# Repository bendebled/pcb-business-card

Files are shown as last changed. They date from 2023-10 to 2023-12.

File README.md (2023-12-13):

# pcb-business-card-micropython

Paper business cards have long been a staple of professional networking, but in today's digital age, they can feel a bit outdated. PCB business card is a more dynamic and innovative alternative that showcases your creativity and technical prowess. While paper business cards are traditional and functional, PCB business cards are undeniably more intriguing, making a lasting impression with their unique blend of design and functionality.

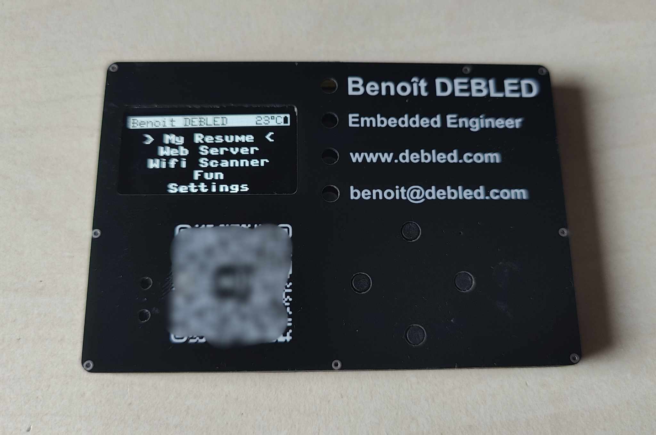
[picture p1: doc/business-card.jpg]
business-card


## Requirements 

Here are the main requirements and features:

1. Usefulness: The PCB business card must break the mold of traditional business cards, ensuring it remains relevant and does not end up in a drawer, forgotten. To achieve this, it will incorporate a range of practical features.
2. Cost-Efficiency: Keeping the project within budget is essential. By selecting cost-effective components and optimizing the design, the aim is to strike a balance between functionality and affordability.
3. Self-Contained Operation: The business card will operate independently, without the need for external devices or connections. It should function as a standalone device, enhancing its versatility and usability.

## Key Features:

* ESP32 Microcontroller: The heart of the card, offering Wi-Fi and Bluetooth capabilities, making it versatile for various projects. Its compatibility with MicroPython allows for easy adaptation.
* OLED Screen Display: A small, yet informative screen to showcase a resume or any other relevant information. A screen is always a valuable addition to any portable project.
* Navigation Buttons: Intuitive buttons for easy screen navigation, ensuring a seamless user experience.
* Temperature Sensor: Practical for various applications, such as a portable thermometer or climate data logging.
* Addressable LED: Adding visual appeal and functionality, the LED can display notifications, status updates, or even be used for creative effects.
* Buzzer: Provides audio feedback, enhancing user interaction and versatility for applications like alarms or notifications.
* Battery-Powered: The card will run on a compact, rechargeable battery LIR2450 , eliminating the need for constant external power sources. This feature allows it to be showcased independently and used in various scenarios, such as a remote control or portable game console.
* Header Pins: Including header pins allows the card to be easily integrated into other projects, extending its functionality beyond a business card.
* MicroPython: MicroPython will accelerate the development process, bringing this project to fruition more efficiently, while also facilitating seamless future firmware customization.

## Component selection

* ESP32-C3: ESP32-C3 is one of the smallest ESP32 chip series, allowing a reduced cost of the project. A module containing the USB-C connector, an LDO regulator, an ESP32-C3, antenna, 2 buttons and breakout pins is used in order to accelerate the development process.
* SSD1306 OLED Screen: This screen is one of the most famous OLED screen in hobbyist projects. The OLED technology will allow a small power consumption.
* WS2812b leds: Those adressable LEDs are affordable and allows to have multiple colors making this PCB business card more versatile
* buttons: regular smd buttons are used in this project. They will be flushed to the top surface making a nice finish. Unfortunately, the ESP32-C3 does not have any touch capable pins making touch buttons more of a hassle as external components necessary.
* passive piezzo buzzer: a very small (5*5*2mm) passive piezzo buzzer will allow multiple tones making it more versatile
* LIR2450 battery: a 120mAH LIR2450 battery will be soldered directly to the PCB without any battery holder in order to gain space
* DS1621 Digital Thermometer: this temperature sensor will give more accurate results than the embedded temperature sensor of the ESP32

## Project structure

This repository contains different folders:

* pcb: contains the different designed PCB using Altium Designer
* src: contains the MicronPython code

## How to make the hardware

* Please produce the 3 different PCB needed for this project: the mainboard, the middle and the top. As the LIR2450 battery is 5mm high, you will need 4 PCB of 1.6mm thick for the middle PCB. There are 3 zip files containing the gerber files; one for each PCB.
* Unsolder the regulator on the ESP32 module. This can be done easily with a hot air gun.
* Solder all components on the mainboard.
* Either connect all PCB by soldering a pin on each visible via or by gluing them together with contact glue. If you choose the glue option, you can still use the via to guide the PCB correctly on top of each other.

## How to deploy the firmware

See [doc/firmware.md](doc/firmware.md) for more details

## How to deploy the micropython app

You can list, get and upload new python file using ampy. To install ampy, please run the following command:

```bash
pip3 install adafruit-ampy
```

To list files, you can run:

```
ampy -p /dev/ttyACM0 ls
```

You should get the following results:

```
/app_secrets.py
/benoit-debled-resume.pdf
/boot.py
/buttons.py
/colorsys.py
/config.py
/display.py
/ds1621.py
/index.html
/led_effect.py
/main.py
/menu.py
/microdot.mpy
/microdot_asyncio.mpy
/music.py
/numberfacts.py
/pong.py
/power_mgmt.py
/resume.py
/settings.py
/sh1106.py
/statemachine.py
/static
/temperature.py
/tetris.py
/webserver.py
```

To deploy the files...TODO

## Yet to test:

* Small PCB were glued vertically between LED lights to avoid any light bleed. However, LED pipes should be placed. A cheap solution to test is to pour transparent silicone inside the fours LED holes.

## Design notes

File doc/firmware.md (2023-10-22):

# Firmware

This project is built on top of MicroPython. As I type those lines, the latest MicroPython version is 1.21 and was released on Oct 6 2023.

However, we can not use the [ESP32-C3 artefact built from MicroPython](https://micropython.org/download/ESP32_GENERIC_C3/) as it misses a [PR](https://github.com/micropython/micropython/pull/9583) that we need for this project. Indeed, the ESP32-C3 does not manage the wake-up events from deepsleep like the other ESP32. Due to this, MicroPython does not implement any wake-up event except timer wake-up. We indeed need to be able to wake up the ESP32 when you press on any buttons.

This documents aims to explain how to correctly build a MicroPython that suits our needs

## Build MicroPython firmware

MicroPython uses the ESP-IDF SDK in order to build ESP32 artefacts. You can see in the `ports/esp32/README.md` file that it uses the 5.0.2 SDK version. You can also see that by running the following lines in the REPL of a flashed firmware on a ESP32-C3 chip:

```python
>>> import platform
>>> platform.platform()
MicroPython-1.21.0-riscv-IDFv5.0.2-with-newlib4.1.0

>>> import os
>>> os.uname()
(sysname='esp32', nodename='esp32', release='1.21.0', version='v1.21.0 on 2023-10-06', machine='ESP32C3 module with ESP32C3')
```

Let's get the micropython repository ready:

```bash
git clone git@github.com:micropython/micropython.git
cd micropython
git checkout v1.21.0
gh pr checkout 9583
git rebase v1.21.0
```

The `ports/esp32/README.md` files explains very well how to build a MicroPython firmware for the ESP32 target, but in a nutshell, here is what you need to do:

```bash
git clone -b v5.0.2 --recursive https://github.com/espressif/esp-idf.git
cd esp-idf
./install.sh
source export.sh

cd ../micropython
make -C mpy-cross
cd ports/esp32
make BOARD=ESP32_GENERIC_C3 submodules
make BOARD=ESP32_GENERIC_C3
```

The generated firmware will be here: `build-ESP32_GENERIC_C3/firmware.bin`

Next step: deploy the firmware to the target!

## Deploy MicroPython firmware

If you are lucky, you can just run the following commands: 

```bash
esptool.py --chip esp32c3 --port /dev/ttyACM0 erase_flash
esptool.py --chip esp32c3 --port /dev/ttyACM0 --baud 460800 write_flash -z 0x0 firmware.bin
```

This works on a non-modified ESP32-C3 module. As soon as I removed the LDO that was on the module, this would not work anymore... Indeed, I would get the following error when running the erase_flash command.

```
Serial port /dev/ttyUSB0
Connecting....
Detecting chip type... Unsupported detection protocol, switching and trying again...
Connecting....
Detecting chip type... ESP8266
Chip is ESP8266EX
Features: WiFi
Crystal is 26MHz
MAC: 34:94:54:61:ac:3b
Uploading stub...
Running stub...
Stub running...

A fatal error occurred: Unable to verify flash chip connection (No serial data received.).
```

The [stub](https://docs.espressif.com/projects/esptool/en/latest/esp32/esptool/flasher-stub.html) seems to be blocked somehow...

By doing what [lewisxhe suggested](https://github.com/Xinyuan-LilyGO/T-Display-S3/issues/162), you should be able to run the erase command

```
insert USB, press and hold BOOT, do not release the boot button, then press RST. Finally, release the boot
```

After this procedure, run the erase_flash command and voilà!

The write_flash command should run without any issue!

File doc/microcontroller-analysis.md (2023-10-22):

# Micro-controller analysis

## Introduction

As stated in the readme.md of the roof of this project, the selected micro-controller should have the following requirements:

* Not only useful for this business card, but also useful for any future use
* cost should not be too high

It is also best if the micro controller does not require a lot of external components in order to eventually reduce the cost and also to reduce the pcb footprint and hassle

For those reasons, ESP32 chip family seems to be a good choice: it has small footprint, not too expensive, has a lot of features such as WiFi, BLE,... Moreover, some of them have an onboard flash and USB making it very small

## ESP32 Chip series comparison

The ideal chip would then be a chip that has USB, onboard flash and small current consumption particularly on sleep mode.

Let's first understand the differenc chip series. [This](https://core-electronics.com.au/guides/esp-32-naming-conventions/) website is quite an help to understand the overall differences:

```
    ESP32-SX versions are the most powerful, most current version of these ESP32 boards that are readily available. These boards may or may not have Bluetooth connectivity.
    The S3 variant in particular are built with Edge AI machine-learned systems in mind.  Edge just means all calculations are done on the hardware, not the cloud, check out the ESP32-S3.
    ESP32-CX versions are the Low Power, Lower Peripheries (IO) boards. They are usually drop-in replacements for the original ESP8266 Module. The ESP8266 Module started production all the way back in 2014. These have Bluetooth and WiFi connectivity. Perfect for battery-powered remote systems where a low current draw for a long life is ideal. A great example of this would be the ESP32-C3.
    ESP32-HX versions are coming soon. Espressif is always innovating and producing new solutions to stay in front of the curve. These are oriented towards IoT applications, the H2 features onboard Zigbee. We try to stay on top as well and as such it is worth noting the ESP32-H2 will be available in the very soon future. This will be the next most powerful ESP32 Board.
```

Seems like an ESP32-C3 is the ideal candidate as it is a chip from the C-series, hence the low power series! The ESP32-C3 has onboard flash, onbaord USB and is very inexpensive,... It can be seen as the next generation of the ESP8266 [[ref](https://hackaday.com/2021/02/08/hands-on-the-risc-v-esp32-c3-will-be-your-new-esp8266/)]

Let's see the ESP32-C3 datasheet compared to the other ESP32 chip series:

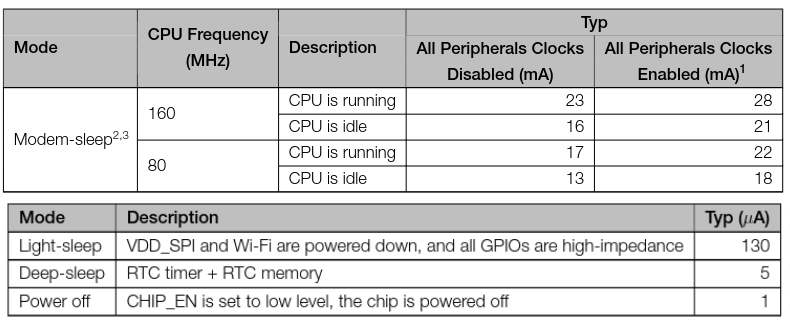
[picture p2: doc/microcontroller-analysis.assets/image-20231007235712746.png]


When the device will be sitting, we should be able to get as low as 5µA which is very good!

On an original ESP32, deep-sleep can go as low as 10µA or can go down to 5µA (hibernation):

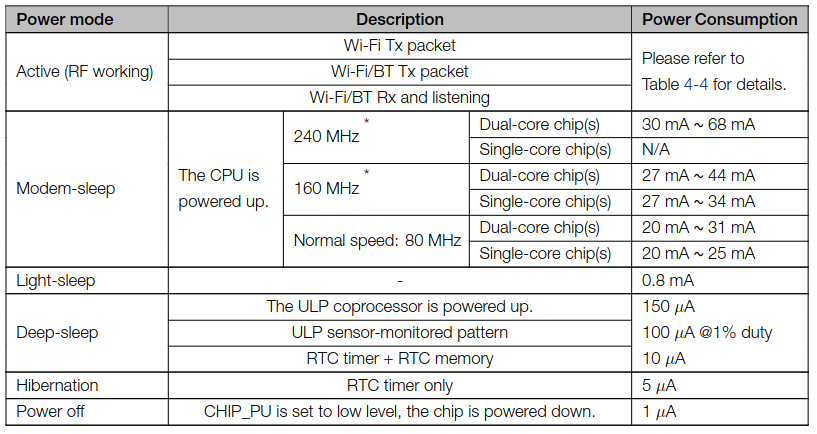
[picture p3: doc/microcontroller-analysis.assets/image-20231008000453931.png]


On the ESP32-S3, deepsleep can go as low as 7µA:

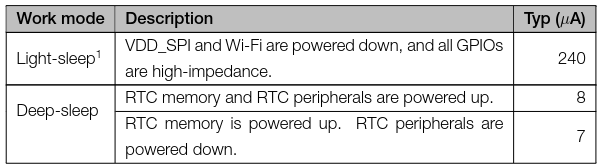
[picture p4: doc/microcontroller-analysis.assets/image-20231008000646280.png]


The following table [[src](https://www.espboards.dev/blog/esp32-soc-options/)] explains very well the differences between the different ESP32 versions

| | ESP32 | ESP32S2 | ESP32S3 | ESP32C2 | ESP32C3 | ESP32C5 | ESP32C6 |
| --- | --- | --- | --- | --- | --- | --- | --- |
| **Release date** | 2016 | 2020 | 2020 | 2022 | 2020 | 2022 | 2021 |
| **Processor** | Xtensa dual-core 32bit LX6 | Xtensa single-core 32bit LX7 | Xtensa dual-core 32bit LX7 | 32bit single-core RISC-V | 32bit single-core RISC-V | 32bit single-core RISC-V | 32bit single-core RISC-V  |
| **Frequency** | 240 MHz | 240MHz | 240 MHz | 120 MHz | 160 MHz | 240 MHz | 160 MHz |
| **SRAM** | 520 KB | 320 KB | 512 KB | 272 KB | 400 KB | 400 KB | 512 KB |
| **ROM** | 448 KB | 128 KB | 384 KB | 576 KB | 384 KB | 384 KB | 320 KB |
| **Flash** | Up to 4 MB | Up to 4 MB | Up to 8 MB | Up to 4 MB | Up to 4 MB | Up to 4 MB | Up to 4 MB |
| **WiFi** | 802.11 b/g/n, 2.4 GHz | 802.11 b/g/n, 2.4 GHz | 802.11 b/g/n, 2.4 GHz | 802.11 b/g/n, 2.4 GHz | 802.11 b/g/n, 2.4 GHz | 802.11 ax, 5.0 GHz | 802.11 ax, 2.4 GHz |
| **Bluetooth** | BLE 4.2 | x | BLE 5.0 | BLE 5.0 | BLE 5.0 | BLE 5.2 | BLE 5.3 |
| **GPIO** | 34 | 43 | 45 | 14 | 22 | 20 | 30 |
| **ADC** | Two 12-bit, 18 channels | Two 13-bit, 20 channels | Two 12-bit, 20 channels | One 12-bit, 5 channels | Two 12-bit, 6 channels | One 12-bit, x channels | One 12-bit, 7 channels |
| **DAC** | Two 8-bit channels | Two 8-bit channels | x | x | x | x | x |
| **SPI** | 4 | 4 | 4 | 3 | 3 | 2 | 2 |
| **I2C** | 2 | 1 | 2 | 1 | 1 | 2 | 2 |
| **I2S** | 2 | 1 | 2 | 1 | 1 | 1 | 1 |
| **RMT** | 8 channels | 4 channels | 8 channels | | 4 channels | 2 channels | 2 channels |
| **Touch sensor** | 10 | 14 | 14 | x | x | x | x |
| **Hall sensor** | 1 | x | x | x | x | x | x |
| **LCD Interface** | 1 | 1 | 1 | x | x | x | x |
| **Camera Interface** | 1 | 1 | 1 | x | x | x | x |
| **Deep sleep** | 100uA | 22uA | 7uA | 5uA | 5uA | 5uA | 7uA |
| **Size** | 5x5mm or 6x6mm | 7x7mm | 7x7mm | 4x4mm | 5x5mm | 5x5mm | 5x5mm |
| **Other features** | | | | | | | 802.15.4 (Thread, Zigbee) |

As it can be seen, the C3 is a good choice as we do not need more than a 802.11 b/g/n wifi, BLE 5.0, 400 KB of RAM and 384 KB of ROM. Moreover, as it is the first one of the series, it is one of the most well known variant and is easy to find on the market!

## ESP32-C3 and deepsleep

Whereas a lot of wake up methods are available on an original ESP32: wake on timer, wake on touch, wake on ulp, wake on ext0, wake on ext1 it is not the case on the ESP32-C3. Indeed, the only possible way to wake up the ESP32-C3 is through a timer or via the pins that are powered by the RTC:



Note that unlike the ESP8266, the ESP32-C3 can sleep indefinitely until you wake it up via one of those pin. You can also technically configure it to sleep forever without any way to wake up unless you reset it.

The only drawback is that it seems that MicroPython does not support wake up on those pins for the ESP32-C3 as it can be seen in the [modmachine.c](https://github.com/micropython/micropython/blob/5232847771903e9022c8c67a436b0562e4530602/ports/esp32/modmachine.c) file: (look at the `#if !CONFIG_IDF_TARGET_ESP32C3` line...). This is not an issue however as it is not impossible! My first thought was to call the correct calls of the ESP-IDF by either modifying the micropython code or by writing [native machine code in .mpy file](https://docs.micropython.org/en/latest/develop/natmod.html) but I will have a look at a current MicroPython [PR](https://github.com/micropython/micropython/pull/9583)

```c
STATIC mp_obj_t machine_sleep_helper(wake_type_t wake_type, size_t n_args, const mp_obj_t *pos_args, mp_map_t *kw_args) {

    ...
    
    mp_int_t expiry = args[ARG_sleep_ms].u_int;

    if (expiry != 0) {
        esp_sleep_enable_timer_wakeup(((uint64_t)expiry) * 1000);
    }   
    
    #if !CONFIG_IDF_TARGET_ESP32C3

    if (machine_rtc_config.ext0_pin != -1 && (machine_rtc_config.ext0_wake_types & wake_type)) { ... }   
    if (machine_rtc_config.ext1_pins != 0) { ... }
    if (machine_rtc_config.wake_on_touch) { ...  }
    if (machine_rtc_config.wake_on_ulp) { ... }

    #endif

    switch (wake_type) {
        case MACHINE_WAKE_SLEEP:
            esp_light_sleep_start();
            break;
        case MACHINE_WAKE_DEEPSLEEP:
            esp_deep_sleep_start();
            break;
    }
    return mp_const_none;
}

```

## ESP32-C3 chip or module?

In order to increase the development speed, a module will be used. Indeed, there are a couple of benefits:

* no need to go through an assembly process, the module can be hand soldered
* some tests can be done on a breadboard before ordering the PCB (current measurements,...)
* no antenna design to be done

but it has also a couple of drawbacks:

*  a little bit more footprint used
* need to remove the default LDO regulator as the quiescent current is way higher than a good old MCP1700 (for example). Moreover, as we want the device to be battery operated, we might want to add a MOSFET in the middle of this.

Without further ado, here is the ESP32-C3 module:

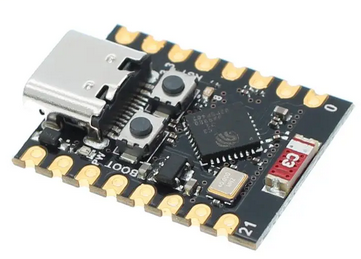
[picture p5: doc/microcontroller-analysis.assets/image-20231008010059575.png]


And here is its schematic:

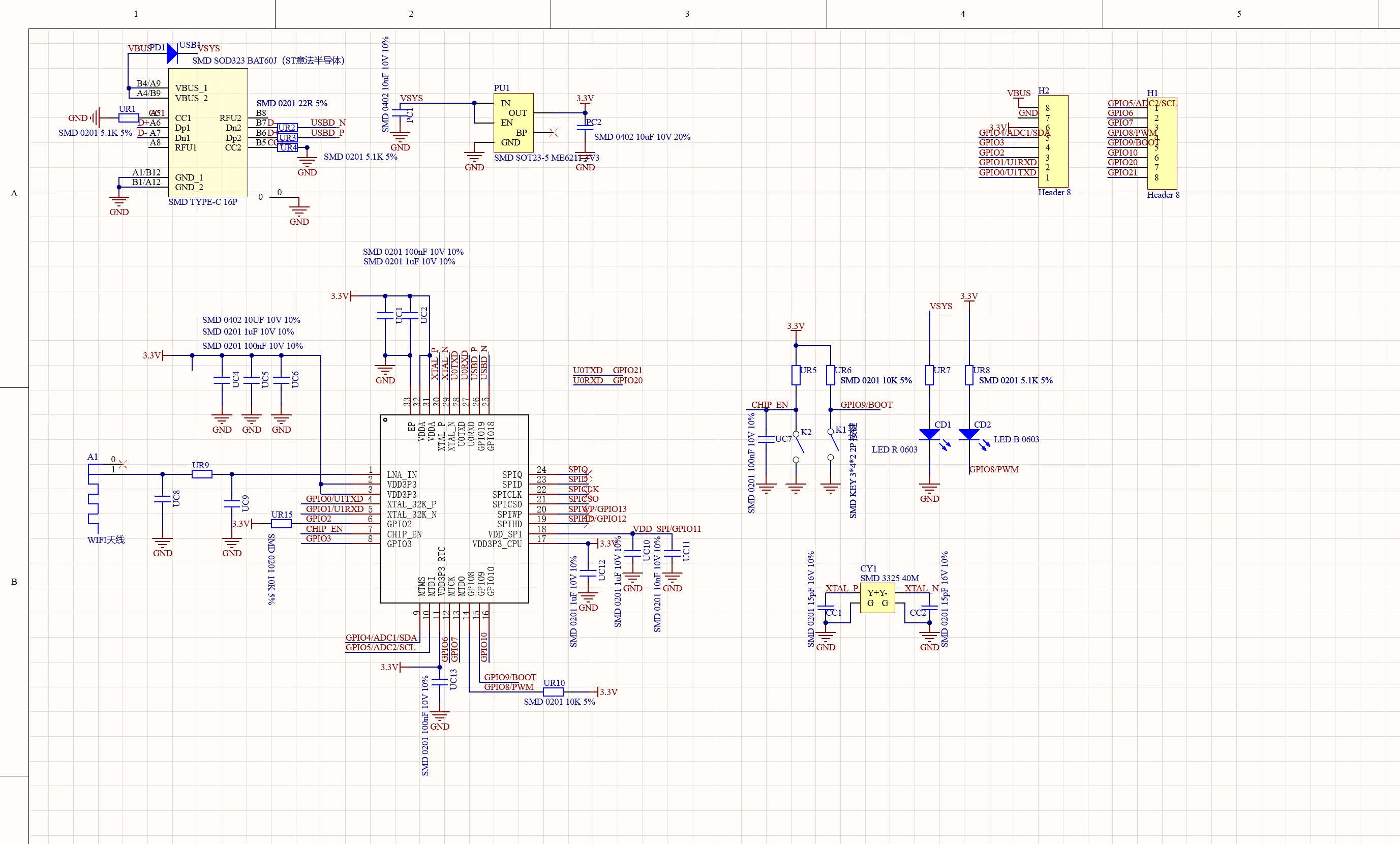
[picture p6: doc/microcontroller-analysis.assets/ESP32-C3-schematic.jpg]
ESP32-C3-schematic


## Pin usage

As I might do the design without having the ESP32-C3 in front of me due to time constraints, it is very important to check that all pins are correctly used!

Here is a table that summarize the pin usage

| Pins | Use | Note |
| --- | --- | --- |
| GPIO0  | Button | VDD_RTC |
| GPIO1  | Button | VDD_RTC |
| GPIO2  | Button | VDD_RTC /!\ Strapping pin |
| GPIO3  | Button | VDD_RTC |
| GPIO4  | Button | VDD_RTC |
| GPIO5  | Battery voltage input | |
| GPIO6  | SCL | /!\ Power glitches (the pin is at a low level output status during 5ns) |
| GPIO7  | SDA | /!\ Power glitches (the pin is at a low level output status during 5ns) |
| GPIO8  | | LED connected /!\ Strapping pin |
| GPIO9  | | Boot button /!\ Strapping pin |
| GPIO10 | Buzzer (through MOSFET) | PWM should be on all GPIO pin /!\ Power glitches (the pin is at a low level output status during 5ns) |
| GPIO20 | WS2812B | /!\ Power glitches (the pin is at a low level output status during 5ns) |
| GPIO21 | Screen/Temp/WS2812B ON/OFF (through 2 MOSFET) | |

This leaves not a lot of free pins! This is one caveat of ESP32-C3: its limited number of pins. There are different solutions if you need more IO: I2C IO expander or shift registers for the cheap way. 74HC166 and 74HC595 are good candidates. Please read this [page](https://diyi0t.com/shift-register-tutorial-for-arduino-and-esp8266/?utm_content=cmp-true) for more information.

Note that the REPL will not be duplicated on UART0 but will only be available through CDC (USB). Indeed, this is well configured in the following file of micropython repository `ports/esp32/boards/GENERIC_C3_USB`: 

```
CONFIG_ESP_CONSOLE_UART_DEFAULT=
CONFIG_ESP_CONSOLE_USB_CDC=
CONFIG_ESP_CONSOLE_USB_SERIAL_JTAG=y
```

## Current analysis

Note on OLED: https://bitbanksoftware.blogspot.com/2019/06/how-much-current-do-oled-displays-use.html

Note on WS2812: https://lowpowerlab.com/forum/general-topics/ws2812b-rgb-led-measurements/

## Conclusion

Long life to the ESP32-C3!

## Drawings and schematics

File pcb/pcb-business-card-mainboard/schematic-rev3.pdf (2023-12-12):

# Power

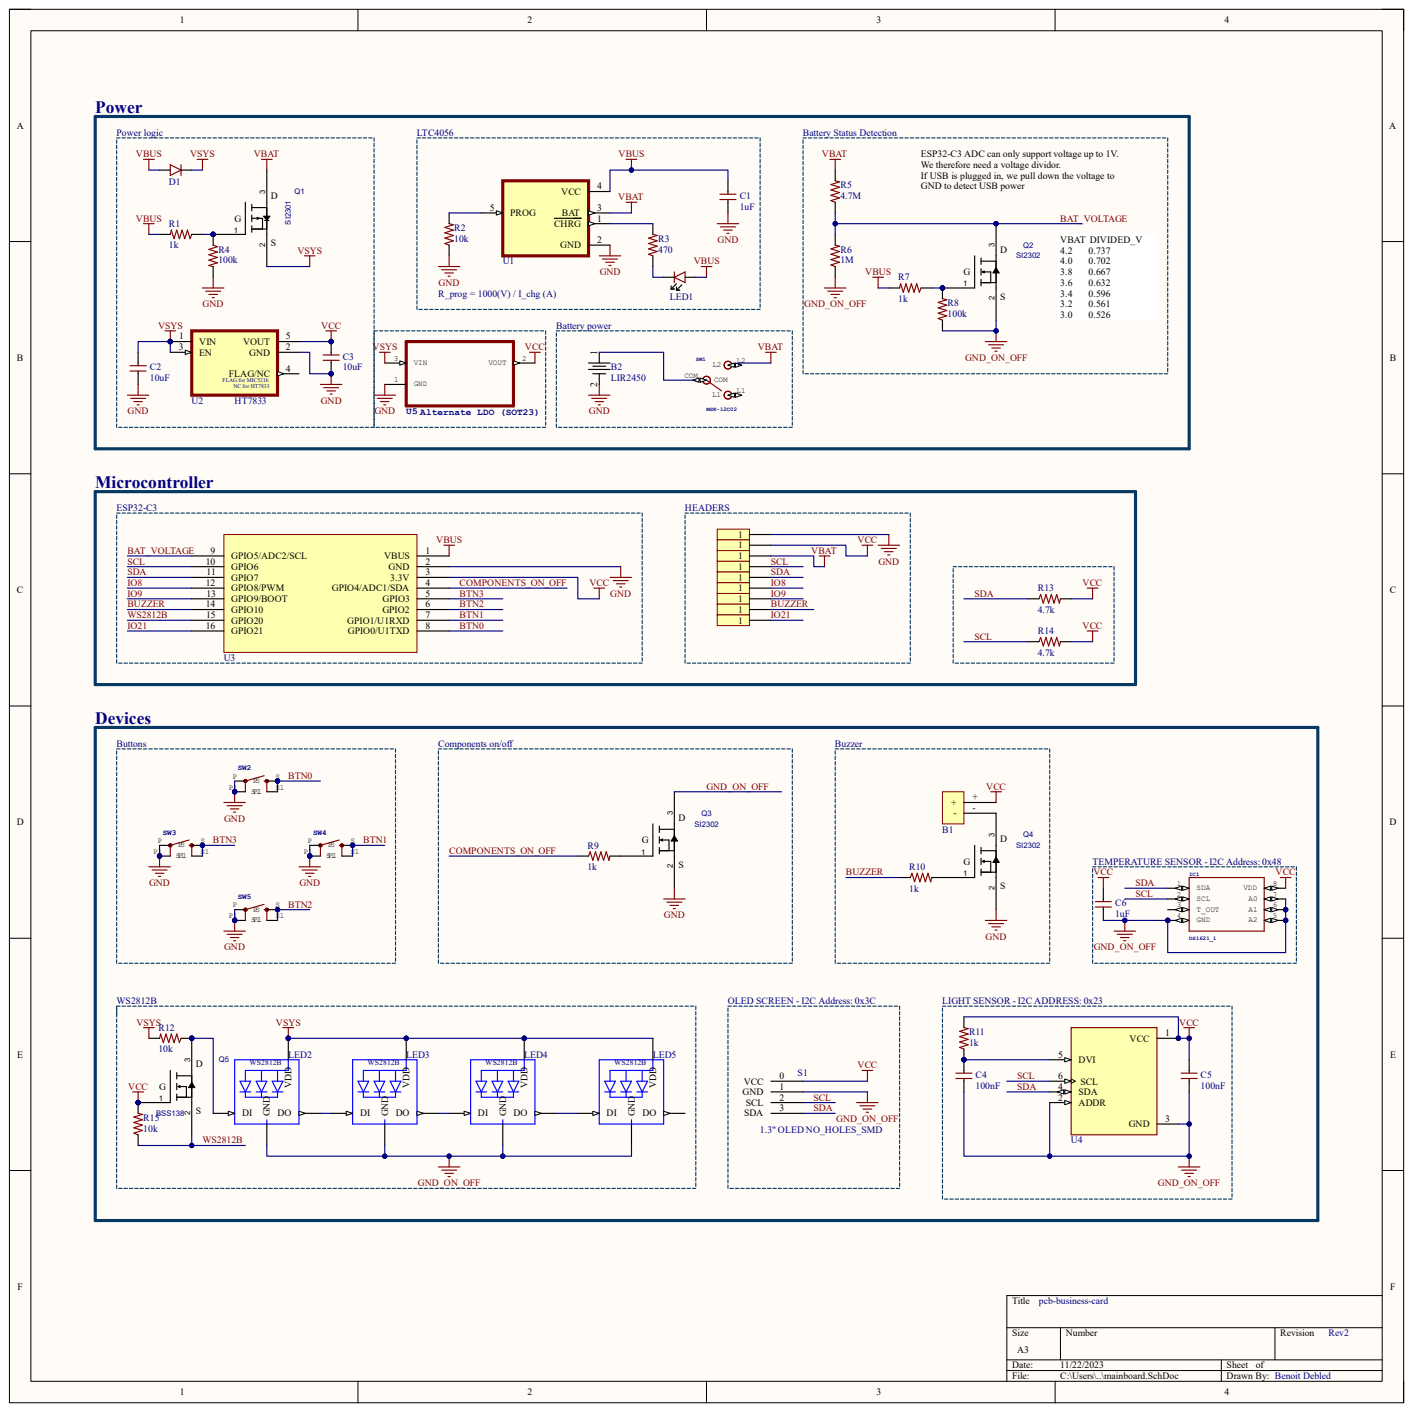
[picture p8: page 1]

ESP32-C3 ADC can only support voltage up to 1V.
We therefore need a voltage dividor.
If USB is plugged in, we pull down the voltage to
GND to detect USB power

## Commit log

2023-10-22 pcb: gitignore
2023-10-22 pcb: project initialized
    [mainboard.SchDoc, pcb-business-card-mainboard.PrjPcb]
2023-10-22 pcb: schematic and PCB design done
    [mainboard.PcbDoc, mainboard.SchDoc, middle.PcbDoc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]
2023-10-22 pcb: gerbers generated
    Gerbers were generated and ready to be sent to JLCPCB.
    Note that the middle board contains actually another project for
    cost reduction reasons.
2023-12-12 pcb: rev2
    Changelog mainboard PCB:
    * ESP32C3 module pins swap
    * LED connected to LTC4054: now properly wired
    * LTC4054: powered via VBUS instead of VSYS to avoid ~33uA consumption
    * R7 and R8 are now respectively 1K and 100K value resistors
    * R7 is now connected to VBUS instead of VSYS
    * WS2812B are now connected to VSYS instead of VBAT
    * Catch phrase's font change
    * PCB now contains a string to specify the location of order number during production
    Changelog top PCB:
    * Some vias were not correctly set to assemble the PCB together
    * PCB now contains a string to specify the location of order number during production
    [mainboard.PcbDoc, mainboard.SchDoc, pcb-business-card-mainboard.PrjPcb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]
2023-12-12 pcb: rev3
    [mainboard.PcbDoc, mainboard.SchDoc, pcb-business-card-mainboard.PrjPcb]
2023-12-24 pcb: rev4
    Buzzer is now connected on GND_ON_OFF
    Pin 1 and 2 of OLED Screen can be now selected to be VCC or GND via jumpers
    [mainboard.PcbDoc, mainboard.SchDoc]
